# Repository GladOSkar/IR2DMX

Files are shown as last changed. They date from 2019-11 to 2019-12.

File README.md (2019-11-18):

# IR2DMX

Project to create a device that allows the triggering of DMX devices using IR blasts/flashes.

Was used in a photoshoot with 2 3kW DMX flashes and a IR studio flash.

## History

Initially was meant to be really simple, just a couple of photodiodes and a RS-485 transceiver.

Feature creep turned it into a big, very adjustable flashy gimmick, as it does.

## Features

- Flash output on 2 configurable main channels
- Adjustable values for 2 more side channels per main channel
- Adjustable IR sensitivity
- Adjustable Pulse length
- PoX (Power over XLR)
- Display with convenient user interface
- Beautiful 3D printable box
- Camera mount compatible

Electronic schematics and 3D models may be uploaded later.

## License

See [LICENSE](LICENSE)

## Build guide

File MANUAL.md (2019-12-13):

IR2DMX Manual
=============

## Introduction and function

The IR2DMX, on triggering, sends out DMX pulses on two dimmer channels which can be configured individually. It can also statically set the two following channels for each of the pulsed channels.

The device is meant to be used with studio IR camera flashes but can also be triggered manually for testing.

All signals for both channels will be output on _both_ XLR jacks. The middle jack is for powering the IR2DMX with the included USB to DMX cable. See below for more info.

## Definitions

There is a left output `L` and a right output `R`. Each of those have three consecutive channels, labelled `D` (Dimmer), `S` (Shutter) and `E` (Effect).

The 6 sliders are, from left to right, referred to as `LD`, `LS`, `LE`, `RD`, `RS`, `RE`.

Meanwhile the four buttons will be `lu` (Left up), `ld` (Left down), `ru` (Right up) and `rd` (Right down).

The small black squares on the side of the device are the IR Sensors.

## Display indicators

By default, the display shows all values currently set for each channel of both outputs. The `L` output is on top and the `R` one below.

When the IR2DMX is triggered, it will display an exclamation mark next to the output label, like so: `L!`, `R!` for the duration of the DMX pulse.

## Setup

Follow these steps to set up your IR2DMX device.

### Mounting

The IR2DMX should be positioned in such a way that the sensors point towards the IR flash. For secure and flexible mounting, you can use the tripod thread on the bottom of the device.

### Power

Connect the middle XLR jack to a power outlet using the included USB to XLR cable and a USB power adaptor. Please only use quality USB power adaptors with 1A+ since we experienced some issues with very cheap ones.

### IR sensitivity

To configure the base settings, press both left buttons (`lu` and `ld`) simultaneously. On the display, the settings menu will appear.

Using the left buttons, you can now adjust the IR sensitivity threshold. To do this, actuate your IR trigger in front of the IR sensors. If an exclamation mark appears on the display, the IR pulse was successfully detected. If not, try lowering the IR sensitivity threshold until the pulse is detected. Then, retreat with your IR flash to your normal distance. Distances up to 10m can work, although outdoors the maximum is usually around 2-3m, with a little more at night. Lower the IR sensitivity threshold until it works at your desired distance. If your device constantly shows the exclamation mark, try heightening the IR sensitivity threshold or shielding the device from potential outside IR influences.

To exit the settings menu, press both left buttons simultaneously again.

### Pulse length

To configure the base settings, press both left buttons (`lu` and `ld`) simultaneously. On the display, the settings menu will appear.

Using the right buttons, you can now adjust the DMX pulse length. Various different devices might need a longer or shorter pulse for proper actuation. The value is displayed in milliseconds.

To exit the settings menu, press both left buttons simultaneously again.

### Channels

To configure the left and right base (dimmer) channels, use the corresponding buttons next to the display. Press and hold a button to scroll channels more quickly.

### DMX wiring

Next, connect your DMX devices. The channel you want to pulse should be the base channel for the output used. If you need to control for example two static channels and the third channel should be pulsed, you need to modify and reflash our open-source firmware for now.

### Channel values

Using the sliders, you can now adjust the channel values. The static channels will be updated on the wire as soon as they are changed using the slider, while the pulsed dimmer channel will only take its value during pulse triggering, and stay 0 otherwise.

### Testing

To test whether the DMX pulse output works if you don't have an IR flash on hand, press both right buttons (`ru` and `rd`) simultaneously. An exclamation mark should be shown on the display and a DMX pulse should be sent to both DMX connectors.

## Usage

Your IR2DMX should be operational now. Whenever the IR flash actuates, the dimmer channels will be set to their slider position's values for the pulse length defined and then jump back to 0.

If there are any problems, feel free to contact us, the creators, using a [GitHub issue](https://github.com/GladOSkar/IR2DMX/issues) or our EMail addresses if you have those.

## Advanced configuration

If our UI/UX is too rigid for your usecases, feel free to modify our firmware.

The firmware is written in Arduino C++ and can be compiled easily using the Arduino IDE. All parametric values can be found at the top of the main source file [IR2DMX.ino](https://github.com/GladOSkar/IR2DMX/blob/master/IR2DMX.ino). The two required dependencies `DmxSimple` and `LiquidCrystal` can be found using the Arduino library manager.

In order to flash the microcontroller, open the IR2DMX using the 4 top-facing screws and then use a mini-USB cable to connect to the controller board inside. Please be careful with the wiring inside though, as the cables are quite short.

When releasing our firmware and your modifications, keep in mind the source code licensing put in place by us in the file [LICENSE](https://github.com/GladOSkar/IR2DMX/blob/master/LICENSE). Out of curiosity we'd gladly hear about all modifications!

## Technical details

More details about the exact wiring and electronics can be found in the code and in the schematic:

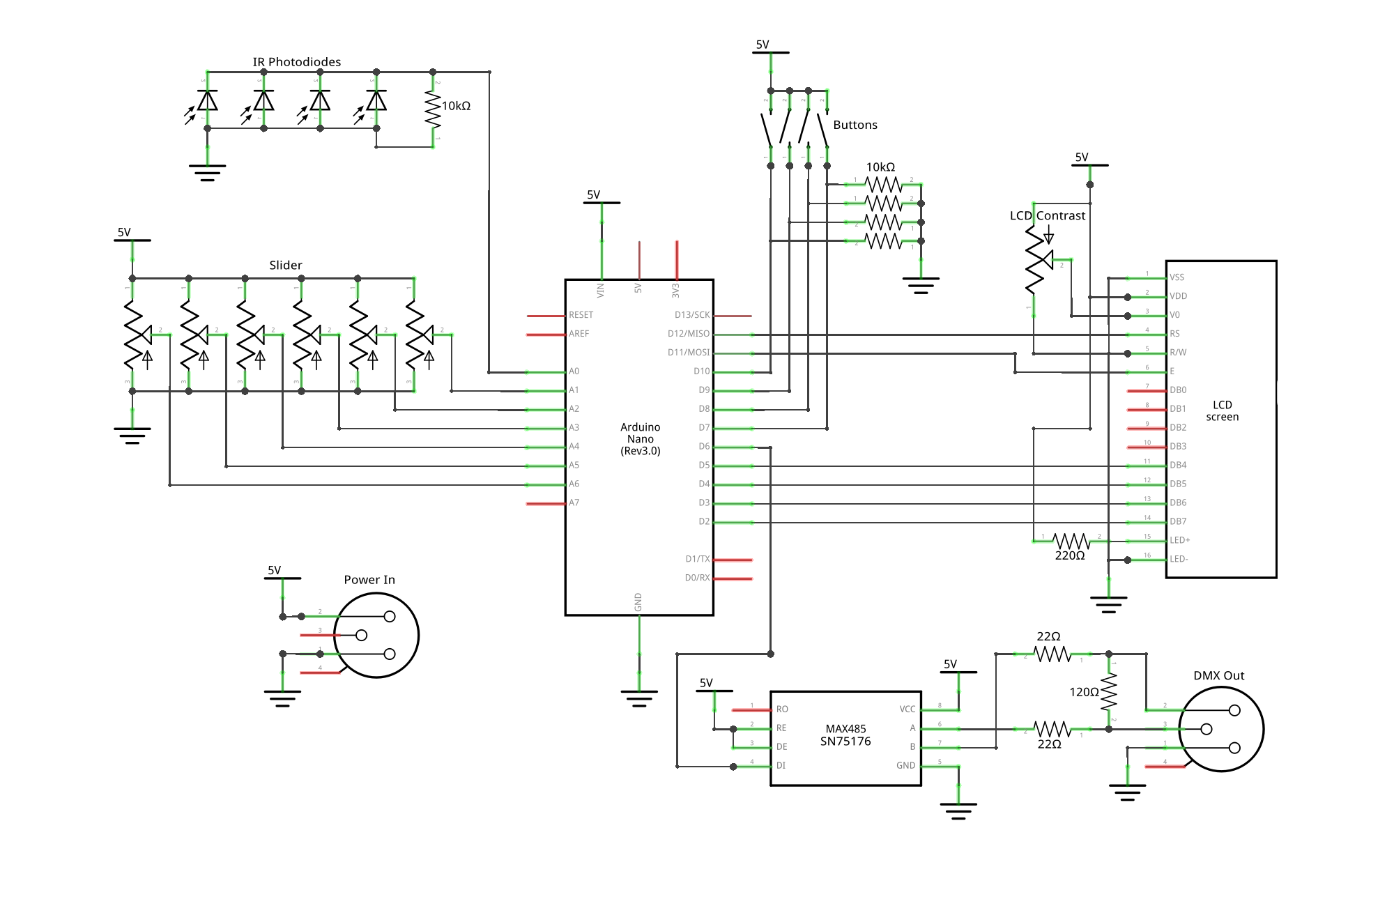
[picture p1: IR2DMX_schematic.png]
IR2DMX Schematic


Parts list:

- Arduino Nano (chinese knockoff)
- RS-485 Transceiver (MAX485 or SN75176)
- Resistors: 5x 10k, 1x220, 1x120, 2x22 Ohms
- 6 10kOhm linear potentiometers
- 1 10kOhm potentiometer (can be replaced with resistors for fixed contrast)
- 4 Buttons
- A bunch of IR photodiodes (Here BP104 because of their wide angle of sensitivity)
- 2 Female XLR jacks
- 1 Male XLR jack

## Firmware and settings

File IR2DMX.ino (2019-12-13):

#include <DmxSimple.h>
#include <LiquidCrystal.h>

#include "IR2DMX.h"

/* TODO:
 *  - Improve structure, split into multiple files
 */

/* HARDWARE NOTES:
 *  - Pin A0 is wired to a bunch of IR Photodiodes in parallel with a fairly big resistor. All to ground.
 *  - Pins A1-A6 are wired to linear potentiometers configured as variable voltage dividers. We used 10k.
 *  - Pins 2-5 are the data pins for the LCD. Exact mappings see below. Use manual.
 *  - Pin 6 is wired to the "Transmit" pin of a RS-485 Transceiver. Hook that up the way the manual says!
 *  - Pins 7-10 are wired to the buttons. Active HIGH. Exact mappings see below.
 *  - Pins 11 and 12 are control pins for the LCD. Exact Mappings see below.
 */

// DMX-512 channels
#define DEFAULT_CH_L 300
#define DEFAULT_CH_R 400
#define MIN_CH 1
#define MAX_CH 512

// How long the display shows currently adjusted values
#define DEFAULT_DISPLAY_TIMEOUT 8000 // loops

// How long the DMX pulse is held
#define DEFAULT_PULSE_LENGTH 2000 // ms
#define STEP_PULSE_LENGTH 100 // ms
#define MIN_PULSE_LENGTH 100 // ms
#define MAX_PULSE_LENGTH 8000 // ms

// At what signal level the IR pulse is registered
#define DEFAULT_SENSITIVITY_THRESHOLD 50 // ??
#define STEP_SENSITIVITY_THRESHOLD 10 // ??
#define MIN_SENSITIVITY_THRESHOLD 10 // ??
#define MAX_SENSITIVITY_THRESHOLD 200 // ??

// How long to press to trigger fast value scrolling
#define PRESS_HOLD_TIMEOUT 3600 // loops
// How long to wait in between values while fast value scrolling
#define PRESS_HOLD_WAIT 16 // ms

// How often the sliders are force-read
#define SLIDER_CHANGE_TIMEOUT_MASK 0b0000011111111111
// How fast the sliders are sampled
#define SLIDER_SAMPLE_TIMEOUT_MASK         0b01111111
// How much the slider value has to change to trigger a repaint
#define SLIDER_CHANGE_THRESHOLD 2

// LCD pins
const int rs = 12, en = 11, d4 = 5, d5 = 4, d6 = 3, d7 = 2;
LiquidCrystal lcd(rs, en, d4, d5, d6, d7);

// Button pins
const int ldButton = 7, luButton = 8, rdButton = 9, ruButton = 10;

// IR Photodiode Pin
const int sensorPin = A0;

void setup(void) {

  // LCD setup
  lcd.begin(16, 2);

  lcd.setCursor(0, 0);
  lcd.print("L D*** S*** E***");
  lcd.setCursor(0, 1);
  lcd.print("R D*** S*** E***");


  //Serial.begin(115200);

  // DMX setup
  DmxSimple.usePin(6);

  // IR Photodiode
  pinMode(sensorPin, INPUT);

  // Slider
  pinMode(A1, INPUT);
  pinMode(A2, INPUT);
  pinMode(A3, INPUT);
  pinMode(A4, INPUT);
  pinMode(A5, INPUT);
  pinMode(A6, INPUT);

  // Buttons
  pinMode(ldButton, INPUT);
  pinMode(luButton, INPUT);
  pinMode(rdButton, INPUT);
  pinMode(ruButton, INPUT);

}

// Prints a number to LCD, 0-Padded to 4 digits
void print4digit(uint16_t nr) {

  if (nr < 1000) lcd.print("0");
  if (nr < 100) lcd.print("0");
  if (nr < 10) lcd.print("0");

  lcd.print(nr, DEC);

}

// Prints a number to LCD, 0-Padded to 3 digits
void print3digit(uint8_t nr) {

  if (nr < 100) lcd.print("0");
  if (nr < 10) lcd.print("0");

  lcd.print(nr, DEC);

}

// Channel data (channels and channel values)
output_t outputs[] = {
  { .channel = DEFAULT_CH_L, .vals = {0, 0, 0} },
  { .channel = DEFAULT_CH_R, .vals = {0, 0, 0} }
};

/*
 * Display Timeout
 * - Control loop decrements once per iteration
 *   - >1 -> Repaints suspended
 *   - =1 -> Repaint triggered
 *   - =0 -> Idle
 */
unsigned int displayTimeoutCounter = 0;

void updateDisplay(void) {

  if (displayTimeoutCounter > 1)
    return;

  lcd.setCursor(0, 0);
  lcd.print("L D");
  print3digit(outputs[L].vals[0]);
  lcd.print(" S");
  print3digit(outputs[L].vals[1]);
  lcd.print(" E");
  print3digit(outputs[L].vals[2]);

  lcd.setCursor(0, 1);
  lcd.print("R D");
  print3digit(outputs[R].vals[0]);
  lcd.print(" S");
  print3digit(outputs[R].vals[1]);
  lcd.print(" E");
  print3digit(outputs[R].vals[2]);

}

void handleTimeout(void) {

  if (displayTimeoutCounter == 1)
    updateDisplay();

  if (displayTimeoutCounter > 0)
    displayTimeoutCounter--;

}

// Sets all current channels to 0
// For when the channel is changed
void clearDMX(void) {

  DmxSimple.write(outputs[L].channel + 0, 0);
  DmxSimple.write(outputs[L].channel + 1, 0);
  DmxSimple.write(outputs[L].channel + 2, 0);

  DmxSimple.write(outputs[R].channel + 0, 0);
  DmxSimple.write(outputs[R].channel + 1, 0);
  DmxSimple.write(outputs[R].channel + 2, 0);

}

// Writes current values to DMX
// For when the channel is changed
void writeDMX(void) {

  DmxSimple.write(outputs[L].channel + 0, outputs[L].vals[0]);
  DmxSimple.write(outputs[L].channel + 1, outputs[L].vals[1]);
  DmxSimple.write(outputs[L].channel + 2, outputs[L].vals[2]);

  DmxSimple.write(outputs[R].channel + 0, outputs[L].vals[0]);
  DmxSimple.write(outputs[R].channel + 1, outputs[L].vals[1]);
  DmxSimple.write(outputs[R].channel + 2, outputs[L].vals[2]);

}

// How long the DMX pulse will be
uint16_t pulseLength = DEFAULT_PULSE_LENGTH; // ms

void triggerDMX(void) {

  // Set main channel
  DmxSimple.write(outputs[L].channel, outputs[L].vals[0]);
  DmxSimple.write(outputs[R].channel, outputs[R].vals[0]);

  // Indicate on screen
  lcd.setCursor(1, 0);
  lcd.print("!");
  lcd.setCursor(1, 1);
  lcd.print("!");

  // Wait for pulse length
  delay(pulseLength);

  // Reset main channel
  DmxSimple.write(outputs[L].channel, 0);
  DmxSimple.write(outputs[R].channel, 0);

  lcd.setCursor(1, 0);
  lcd.print(" ");
  lcd.setCursor(1, 1);
  lcd.print(" ");
  
}

void updateChannel(lr_t lr) {

  // Show main channel number on screen
  lcd.setCursor(2, lr);
  lcd.print("CH:           ");
  lcd.setCursor(6, lr);
  lcd.print(outputs[lr].channel, DEC);

  // Suspend slider repaints for a while
  displayTimeoutCounter = DEFAULT_DISPLAY_TIMEOUT;

}

// Amplitude threshold for IR Photodiodes
uint8_t sensitivityThreshold = DEFAULT_SENSITIVITY_THRESHOLD;

// Whether the settings screen should be displayed
bool settingsMode = false;

// Repaints the setting values
void paintSettingsValues(void) {

  lcd.setCursor(3, 1);
  print3digit(sensitivityThreshold);
  lcd.setCursor(10, 1);
  print4digit(pulseLength);

}

// Switch between normal and settings mode
void changeSettingsMode(void) {

  // Flip
  settingsMode = !settingsMode;

  if (settingsMode) {

    // Paint settings screen
    lcd.setCursor(0, 0);
    lcd.print("  Sensi: PlsLen:");
    lcd.setCursor(0, 1);
    lcd.print("                ");
    
    paintSettingsValues();
    
  } else {

    // Reset display
    updateDisplay();

  }

}

// Set to true to ignore next buttonRelease event
bool preventNext = false;

// Commits and checks button value adjustments
void changeVal(lr_t lr, int8_t delta) {

  // Respect preventNext (s.a.)
  if (preventNext) {
    preventNext = false;
    return;
  }

  if (settingsMode) {

    if (lr == L) {

      // Change sensitivity

      // Check for limits
      if (sensitivityThreshold <= MIN_SENSITIVITY_THRESHOLD && delta < 0)
        return;

      if (sensitivityThreshold >= MAX_SENSITIVITY_THRESHOLD && delta > 0)
        return;

      // Change value
      sensitivityThreshold += STEP_SENSITIVITY_THRESHOLD * delta;
      
    } else if (lr == R) {

      // Change pulse length

      // Check for limits
      if (pulseLength <= MIN_PULSE_LENGTH && delta < 0)
        return;

      if (pulseLength >= MAX_PULSE_LENGTH && delta > 0)
        return;

      // Change value
      pulseLength += STEP_PULSE_LENGTH * delta;
      
    }

    paintSettingsValues();
    
    return;

  }

  // Check for limits
  // I know i should probably abstract this into a bounded data structure
  if (outputs[lr].channel == MIN_CH && delta < 0)
    return;

  if (outputs[lr].channel == MAX_CH && delta > 0)
    return;

  // Zero old channels
  clearDMX();

  // Change channel
  outputs[lr].channel += delta;
  updateChannel(lr);

  // Update new channels
  writeDMX();

  // Limit "Press & Hold" speed
  delay(PRESS_HOLD_WAIT);

}

// Timeout counters for "press & hold" feature
// Double as 'prev' values
uint16_t  cld = 0,
          clu = 0,
          crd = 0,
          cru = 0;

// Check all buttons for inputs and react
void handleButtons(void) {

  // Read current button state
  bool  ld = (digitalRead(ldButton) == HIGH),
        lu = (digitalRead(luButton) == HIGH),
        rd = (digitalRead(rdButton) == HIGH),
        ru = (digitalRead(ruButton) == HIGH);

  // "Both left"
  // One of the left buttons is released when they were both pressed before
  if ((!ld || !lu) && (cld && clu)) {
    
    changeSettingsMode();
    preventNext = true;
    
  }

  // "Both right"
  // One of the right buttons is released when they were both pressed before
  else if ((!rd || !ru) && (crd && cru)) {
    
    triggerDMX();
    preventNext = true;
    
  }

  else {

    // Button is released and was pressed before
    // OR is pressed and was held for a while
    if ((!ld && cld) || (ld && cld > PRESS_HOLD_TIMEOUT))
      changeVal(L, -1);

    if ((!lu && clu) || (lu && clu > PRESS_HOLD_TIMEOUT))
      changeVal(L, +1);

    if ((!rd && crd) || (rd && crd > PRESS_HOLD_TIMEOUT))
      changeVal(R, -1);

    if ((!ru && cru) || (ru && cru > PRESS_HOLD_TIMEOUT))
      changeVal(R, +1);

  }

  // Update timeout counters
  cld = ld ? cld + 1 : 0;
  clu = lu ? clu + 1 : 0;
  crd = rd ? crd + 1 : 0;
  cru = ru ? cru + 1 : 0;

}

// Timeout for when the final measured value settles in
uint16_t sliderTimeout = 255;

// Timeout for how fast to sample slider values for difference measurement for avoiding jitter
uint8_t sampleTimeout = 255;

// Previous values for all sliders to measure difference to avoid jitter
uint8_t pV[2][3];

// Check sliders for inputs and react
void handleSliders(void) {

  // Do not measure and repaint slider values if repaints are suspended
  if (displayTimeoutCounter > 0)
    return;

  // Do not measure and repaint slider values if settings menu is visible
  if (settingsMode)
    return;

  // Save current values into previous for comparison once every short while
  if (sampleTimeout == 0) {
    memcpy(pV[L], outputs[L].vals, 3);
    memcpy(pV[R], outputs[R].vals, 3);
  }

  // Read analog values
  outputs[L].vals[0] = analogRead(A1) / 4;
  outputs[L].vals[1] = analogRead(A2) / 4;
  outputs[L].vals[2] = analogRead(A3) / 4;
  outputs[R].vals[0] = analogRead(A4) / 4;
  outputs[R].vals[1] = analogRead(A5) / 4;
  outputs[R].vals[2] = analogRead(A6) / 4;

  // Update timeout counters
  sliderTimeout = (sliderTimeout + 1) & SLIDER_CHANGE_TIMEOUT_MASK;
  sampleTimeout = (sampleTimeout + 1) & SLIDER_SAMPLE_TIMEOUT_MASK;

  // Update screen values only after a while or on significant change to avoid flickering/jitter
  if ( sliderTimeout == 0 || abs( (int) outputs[L].vals[0] - pV[L][0] ) > SLIDER_CHANGE_THRESHOLD ) {
  
    lcd.setCursor(3, 0);
    print3digit(outputs[L].vals[0]);
  
  }
  
  if ( sliderTimeout == 0 || abs( (int) outputs[L].vals[1] - pV[L][1] ) > SLIDER_CHANGE_THRESHOLD ) {
    
    lcd.setCursor(8, 0);
    print3digit(outputs[L].vals[1]);

    // Also update DMX signal for non-main channels
    DmxSimple.write(outputs[L].channel + 1, outputs[L].vals[1]);
    
  }
  
  if ( sliderTimeout == 0 || abs( (int) outputs[L].vals[2] - pV[L][2] ) > SLIDER_CHANGE_THRESHOLD ) {
    
    lcd.setCursor(13, 0);
    print3digit(outputs[L].vals[2]);
    DmxSimple.write(outputs[L].channel + 2, outputs[L].vals[2]);
    
  }

  if ( sliderTimeout == 0 || abs( (int) outputs[R].vals[0] - pV[R][0] ) > SLIDER_CHANGE_THRESHOLD ) {
  
    lcd.setCursor(3, 1);
    print3digit(outputs[R].vals[0]);
  
  }
  
  if ( sliderTimeout == 0 || abs( (int) outputs[R].vals[1] - pV[R][1] ) > 2 ) {
    
    lcd.setCursor(8, 1);
    print3digit(outputs[R].vals[1]);
    DmxSimple.write(outputs[R].channel + 1, outputs[R].vals[1]);
    
  }
  
  if ( sliderTimeout == 0 || abs( (int) outputs[R].vals[2] - pV[R][2] ) > 2 ) {
    
    lcd.setCursor(13, 1);
    print3digit(outputs[R].vals[2]);
    DmxSimple.write(outputs[R].channel + 2, outputs[R].vals[2]);
    
  }

  /*
  Serial.print(outputs[L].vals[0]);
  Serial.print(",");
  Serial.print(outputs[L].vals[1]);
  Serial.print(",");
  Serial.print(outputs[L].vals[2]);
  Serial.print(",");
  Serial.print(outputs[R].vals[0]);
  Serial.print(",");
  Serial.print(outputs[R].vals[1]);
  Serial.print(",");
  Serial.print(outputs[R].vals[2]);
  Serial.print("\n");
  */

}

// Current IR Photodiode value
uint16_t sensorValue = 0;

// Check IR Photodiodes for inputs and react
void handleIR(void) {

  // save previous value to measure difference
  uint16_t pSensorValue = sensorValue;

  // Read IR value
  sensorValue = analogRead(sensorPin);

  //Serial.println(sensorValue);

  // Trigger on rise over threshold
  if (sensorValue > sensitivityThreshold && pSensorValue < sensitivityThreshold) {

    // Send DMX pulse on main channel
    triggerDMX();

  }

}

// Control loop
// Orchestrates subsystems to check their inputs and react accordingly
void loop(void) {

  handleButtons();

  handleTimeout();

  handleSliders();

  handleIR();

}
